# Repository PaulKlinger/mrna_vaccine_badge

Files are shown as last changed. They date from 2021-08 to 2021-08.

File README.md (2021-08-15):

# mRNA vaccine badge

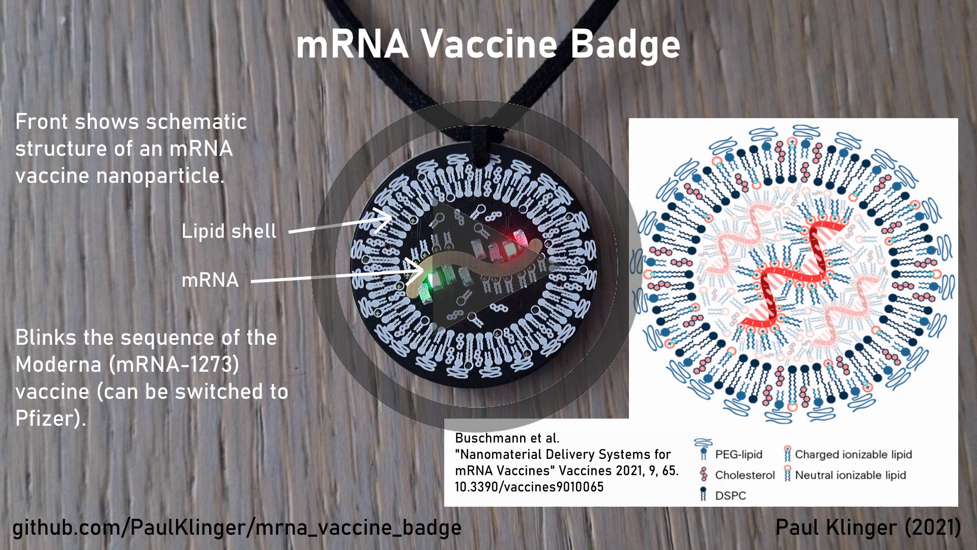
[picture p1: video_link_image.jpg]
(https://youtu.be/r8VF4bMJ7uo "Project video")


A small badge showing a schematic of an mRNA vaccine nanoparticle and blinking the RNA sequence of the Moderna or Pfizer vaccines. (Switch between vaccines by long pressing (>1s) the button to enter the menu, short pressing to switch, and long pressing to save).

The RNA for the moderna vaccine is from is from https://github.com/NAalytics/Assemblies-of-putative-SARS-CoV2-spike-encoding-mRNA-sequences-for-vaccines-BNT-162b2-and-mRNA-1273 with an added poly-A tail of similar length to the Pfizer one (just a guess). The Pfizer sequence is from https://berthub.eu/articles/11889.doc

The sequences are stored encoded into 2 bits per nucleotide using [encode_genome.py](encode_genome.py).

Current draw is ~3mA depending on which color LEDs are active at the moment (the blue ones are a lot more efficient than the red ones). A CR2032 coin cell should last for at least 10h of continuous use (one run through the sequence takes ~10min, and it automatically shuts off afterwards).
Standby current draw is ~0.15µA, should last basically forever (years).

### Components:

- 1 x ATtiny1617 MCU
- 1 x SMD button (SMD-BUTTON(2P-3.0X2.5X1.2+0.4MM)-B3U-1000P-2P-SMD)
- 1 x CR2032 Coin cell clip
- 2 x blue 0805 LED
- 2 x green 0805 LED
- 2 x yellow 0805 LED
- 2 x red 0805 LED
- 2 x 2.2kΩ 0805 resistor (for green LEDs)
- 2 x 910Ω 0805 resistor (for blue LEDs)
- 2 x 470Ω 0805 resistor (for red LEDs)
- 2 x 240Ω 0805 resistor (for yellow LEDs)

There's a footprint for a ceramic capacitor, but it's not needed and I had issues with leakage current with cheap chinese ones (even 1µA really hurts the standby lifetime). 

(The one in the video has wrong (lower) resistor values, which burns a lot more power for negligible increase in brightness.)

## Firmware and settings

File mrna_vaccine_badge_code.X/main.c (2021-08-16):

#include "config.h"

#include <stdbool.h>
#include <util/delay.h>
#include <avr/sleep.h>
#include <avr/io.h>
#include <avr/interrupt.h>

#include "button.h"
#include "sequence.h"
#include "moderna_sequence.h"
#include "pfizer_sequence.h"


FUSES = 
{
	.APPEND = 0,
	.BODCFG = ACTIVE_DIS_gc | LVL_BODLEVEL0_gc | SAMPFREQ_1KHZ_gc | SLEEP_DIS_gc,
	.BOOTEND = 0,
	.OSCCFG = FREQSEL_16MHZ_gc,
	.SYSCFG0 = CRCSRC_NOCRC_gc | RSTPINCFG_UPDI_gc,
	.SYSCFG1 = SUT_64MS_gc,
	.WDTCFG = PERIOD_OFF_gc | WINDOW_OFF_gc,
};

void switch_off_leds() {
    VPORTA.OUT = 255;
    VPORTB.OUT = 255;
}

void go_to_sleep(){
    while (~PORTB.IN & PIN2_bm) {}
    _delay_ms(50);
    switch_off_leds();
    /* disable periodic interrupt, so it doesn't wake up MCU */
    RTC.PITCTRLA &= ~RTC_PITEN_bm;
    _delay_ms(100);
    set_sleep_mode(SLEEP_MODE_PWR_DOWN);
    sleep_enable();
    sleep_cpu();
    while (~PORTB.IN & PIN2_bm) {}
    _delay_ms(50);
    button_released = 0;
    /* enable periodic interrupt again */
    RTC.PITCTRLA |= RTC_PITEN_bm;
}


void show_bases(Base b1, Base b2) {
    VPORTA.OUT = 255;
    VPORTB.OUT = 255;
    switch (b1) {
        case A: // green
            // cast to prevent warning caused by integer promotion to signed...
            VPORTB.OUT &= ~PIN6_bm;
            break;
        case C: // blue
            VPORTB.OUT &= ~PIN4_bm;
            break;
        case G: // yellow
            VPORTA.OUT &= ~PIN4_bm;
            break;
        case T: // red
            VPORTA.OUT &= ~PIN6_bm;
            break;
    }
    
    switch (b2) {
        case A: // green
            // cast to prevent warning caused by integer promotion to signed...
            VPORTB.OUT &= ~PIN7_bm;
            break;
        case C: // blue
            VPORTB.OUT &= ~PIN5_bm;
            break;
        case G: // yellow
            VPORTA.OUT &= ~PIN5_bm;
            break;
        case T: // red
            VPORTA.OUT &= ~PIN7_bm;
            break;
    }
};


const struct sequence *select_sequence(struct config cfg) {
    if (cfg.sequence == MODERNA) {
        return &moderna_sequence;
    } else if (cfg.sequence == PFIZER) {
        return &pfizer_sequence;
    }
    /* this should never happen */ 
    while(1){}
}


void sequence_select_menu(struct config *cfg) {
    while (1) {
        if (button_released > LONG_PRESS_LENGTH) {
            button_released = 0;
            save_config(*cfg); // store config in EEPROM
            break; // start displaying sequence
        } else if (button_released) {
            button_released = 0;
            if (cfg->sequence == MODERNA) {
                cfg->sequence = PFIZER;
            } else if (cfg->sequence == PFIZER) {
                cfg->sequence = MODERNA;
            }
        }
        if (cfg->sequence == MODERNA) {
            VPORTB.OUT = 255;
            VPORTA.OUT = (uint8_t) ~(PIN4_bm | PIN5_bm | PIN6_bm | PIN7_bm);
        } else if (cfg->sequence == PFIZER) {
            VPORTA.OUT = 255;
            VPORTB.OUT = (uint8_t) ~(PIN4_bm | PIN5_bm | PIN6_bm | PIN7_bm);
        }
    }
}


int main(void) {
    
    /* Configure clock prescaler for 1MHz  */
    _PROTECTED_WRITE(
    CLKCTRL.MCLKCTRLB,
    CLKCTRL_PDIV_16X_gc /* Prescaler division: 16X */
    | CLKCTRL_PEN_bm /* Prescaler enable: enabled */
    );
    
    
    /* Enable pullups for low power consumption (20uA -> 0.1uA (afair))*/
    PORTA.PIN0CTRL |= PORT_PULLUPEN_bm;
    PORTA.PIN1CTRL |= PORT_PULLUPEN_bm;
    PORTA.PIN2CTRL |= PORT_PULLUPEN_bm;
    PORTA.PIN3CTRL |= PORT_PULLUPEN_bm;
    PORTA.PIN4CTRL |= PORT_PULLUPEN_bm;
    PORTA.PIN5CTRL |= PORT_PULLUPEN_bm;
    PORTA.PIN6CTRL |= PORT_PULLUPEN_bm;
    PORTA.PIN7CTRL |= PORT_PULLUPEN_bm;
    
    PORTB.PIN0CTRL |= PORT_PULLUPEN_bm;
    PORTB.PIN1CTRL |= PORT_PULLUPEN_bm;
    PORTB.PIN2CTRL |= PORT_PULLUPEN_bm;
    PORTB.PIN3CTRL |= PORT_PULLUPEN_bm;
    PORTB.PIN4CTRL |= PORT_PULLUPEN_bm;
    PORTB.PIN5CTRL |= PORT_PULLUPEN_bm;
    PORTB.PIN6CTRL |= PORT_PULLUPEN_bm;
    PORTB.PIN7CTRL |= PORT_PULLUPEN_bm;
    
    PORTC.PIN0CTRL |= PORT_PULLUPEN_bm;
    PORTC.PIN1CTRL |= PORT_PULLUPEN_bm;
    PORTC.PIN2CTRL |= PORT_PULLUPEN_bm;
    PORTC.PIN3CTRL |= PORT_PULLUPEN_bm;
    PORTC.PIN4CTRL |= PORT_PULLUPEN_bm;
    PORTC.PIN5CTRL |= PORT_PULLUPEN_bm;
    
    
    VPORTB.DIR = (PIN4_bm | PIN5_bm | PIN6_bm | PIN7_bm);
    VPORTA.DIR = (PIN4_bm | PIN5_bm | PIN6_bm | PIN7_bm);
    
    
    /* Enable interrupt on power button
     * (this is only for wakeup)*/
    PORTB.PIN2CTRL = (PORTB.PIN2CTRL & ~PORT_ISC_gm) | PORT_ISC_BOTHEDGES_gc;
    
    init_button();
    sei();
    
    struct config cfg = load_config();
    
    go_to_sleep();
    
    while (1) {
        const struct sequence *current_sequence = select_sequence(cfg);
        for (uint32_t i=0; i< current_sequence->n_bases - 1; i++) {
            show_bases(
                    read_base(current_sequence, i),
                    read_base(current_sequence, i + 1)
                    );
            _delay_ms(LIGHT_DURATION_MS);
            switch_off_leds();
            if (button_released) {
                break;
            }
            _delay_ms(INTERVAL_DURATION_MS);
        }
        
        if (button_released > LONG_PRESS_LENGTH) {
            button_released = 0;
            // long press, switch between sequences
            sequence_select_menu(&cfg);
        } else {
            button_released = 0;
            go_to_sleep();
        }
    }
}

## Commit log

2021-07-04 code for v1.0 (same color leds on one pin)
2021-07-04 added v1.0 PCB files
    [moderna_badge v17.GBL, moderna_badge v17.GBO, moderna_badge v17.GBP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]
2021-07-04 added v1.1 pcb files
    [moderna_badge v21.GBL, moderna_badge v21.GBO, moderna_badge v21.GBP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]
2021-07-04 added moderna sequence (from https://github.com/NAalytics/Assemblies-of-putative-SARS-CoV2-spike-encoding-mRNA-sequences-for-vaccines-BNT-162b2-and-mRNA-1273)
2021-07-04 updated gerbers (color legend)
    [moderna_badge v21.GBO, moderna_badge v22.GBL, moderna_badge v22.GBO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]
2021-07-18 added button debouncing & long press detection
2021-07-18 added pfizer sequence, basic menu to switch between sequences
2021-07-31 updated for v1.1 (individual led control)
2021-08-15 added eagle files
    [mrna_badge.sch]
2021-08-15 renamed gerbers & cam
    [moderna_badge v17.GBL, moderna_badge v17.GBO, moderna_badge v17.GBP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]
2021-08-15 removed outdated files
    [moderna_badge v22.GBL, moderna_badge v22.GBO, moderna_badge v22.GBP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]
2021-08-16 replaced eagle files with backward compatible versions
    [mrna_badge.sch]
2021-08-16 removed spurious trace & via from pcb
    [mrna_badge.GBL, mrna_badge.GTL, mrna_badge.GTS]
